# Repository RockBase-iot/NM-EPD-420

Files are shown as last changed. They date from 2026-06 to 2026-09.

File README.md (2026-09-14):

# NM-EPD-420

The **NM-EPD-420** is an **ESP32-S3** based 4.2-inch tri-color E-ink development board. It integrates Wi-Fi / BLE, LoRa, audio codec, temperature/humidity sensing, SD card, battery management, and other common peripherals — a ready-to-use hardware platform for low-power info panels, weather stations, Meshtastic terminals, dashboards, and more.

> The firmware in this repository is a **factory test firmware**. Its only purpose is to help the production line or a developer quickly verify that all on-board peripherals work after powering on. See [Section 4](#4-factory-test-firmware) for the test sequence, workflow, and build instructions.
>
> 中文版本: [README_cn.md](README_cn.md)

---

## 1. Board overview

The NM-EPD-420 packs the core resources needed for E-ink projects onto a single board:

* **MCU**: ESP32-S3 (16 MB Flash, PSRAM, dual-core 240 MHz, 2.4 GHz Wi-Fi and BLE 5)
* **Display**: 4.2" 400×300 tri-color E-ink panel (black / white / red), model **GDEY042Z98**; black-and-white E-ink panel (GxEPD2_420_GYE042A87); and a four-color panel (black / white / red / yellow, GxEPD2_420c_GDEY0420F51). All three use the same pin definitions, but the controller protocol must match — select the variant according to the panel actually fitted.
* **Audio**: ES8311 audio codec + external Class-D amplifier + onboard speaker, plus an LMD4737 PDM digital microphone
* **Environment sensor**: AHT20 temperature/humidity sensor with independent power switch
* **Wireless extension**: Header for **SX126x** family LoRa modules (shares SPI bus with the SD card) (optional)
* **Storage & I/O**: µSD card slot, USER / BOOT buttons, battery ADC, JST 1.25 2-Pin battery connector
* **Low-power design**: Independent enable pins for each peripheral module allow complete power-down before ESP32 deep sleep

You can run one of the already-supported projects listed below, or treat the NM-EPD-420 as a general ESP32-S3 carrier and start your own application using the pin definitions in this document.

### Display refresh performance

The NM-EPD-420 currently supports the tri-color GDEY042Z98 panel, the black-and-white GYE042A87 panel, and the four-color GDEY0420F51 panel. Their refresh characteristics are as follows:

- **GDEY042Z98 tri-color panel**:
  - **SKU: NM-EPD-420**
  - Full refresh (black / white / red) takes approximately 10 seconds; partial refresh is not supported.
  - The tri-color panel provides richer visuals for weather stations, dashboards, and similar applications, but refreshes more slowly and is best suited to mostly static content.
  - The standard NM-EPD-420 tri-color version does not include a LoRa module and is intended for general desktop applications.

- **GYE042A87 black-and-white panel**:
  - **SKU: NM-EPD-420-BW**
  - Full refresh (black / white) takes approximately 2-3 seconds, with partial refresh supported in approximately 1 second (download [nm-epd420-bw-demo](https://github.com/RockBase-iot/nm-epd420-bw-demo) to try it).
  - The black-and-white panel is recommended for applications that need faster content updates.
  - The NM-EPD-420-BW version is suitable for fast-refresh applications and includes LoRa support by default, making it suitable for indoor desktop LoRa nodes.

- **GDEY0420F51 four-color panel**:
  - **SKU: NM-EPD-420-4C**
  - Full refresh (black / white / red / yellow) takes approximately 25-30 seconds; partial refresh is not supported.
  - The four-color panel is recommended for applications that need more colors and do not require frequent updates.
  - **Build environment: `nm-epd-420-4c`**; driver: `GxEPD2_420c_GDEY0420F51` (400×300, black / white / red / yellow).
  - Build with `pio run -e nm-epd-420-4c`; T1 checks white, black, red, and yellow full-screen fills, then black/red/yellow text.

The NM-EPD-420 base board has also been validated with a 7.5-inch tri-color panel (GxEPD2_750c_Z08, GD7965 controller). The test confirmed base-board compatibility and driver feasibility — content refreshes and displays normally.
*Note: the 7.5-inch panel is not the standard panel shipped with NM-EPD-420 and is used for testing only. For real applications, adjust the case and mechanical structure as needed.*

---

## 2. Already supported open-source projects

The following projects have been ported to the NM-EPD-420. Clone the linked branch and build:

| Project | Description | Adapted repository / branch |
|---|---|---|
| **Meshtastic** | Off-grid LoRa mesh messaging; shows node info, messages, and sensor data on the 4.2" E-ink panel (HT-RA62 module, SX1262) | [RockBase-iot/meshtastic-firmware@`nm-epd-420`](https://github.com/RockBase-iot/meshtastic-firmware/tree/nm-epd-420) |
| **TRMNL-Firmware** | TRMNL E-ink content framework; fetches images/content from a server on a schedule | [RockBase-iot/trmnl-firmware](https://github.com/RockBase-iot/trmnl-firmware) |
| **Biscuit** | Multi-purpose tool / entertainment firmware for E-ink devices | [RockBase-iot/biscuit@`master`](https://github.com/RockBase-iot/biscuit/tree/master) |
| **ESP32-weather-epd** | Low-power weather station; fetches data from OpenWeatherMap and displays it on E-ink | [RockBase-iot/esp32-weather-epd@`main`](https://github.com/RockBase-iot/esp32-weather-epd/tree/main) |
| **ESP32-Dashboard** | Multi-function E-ink dashboard: weather, air quality, indoor T/RH, Web config portal, etc. | [RockBase-iot/ESP32-Dashboard@`main`](https://github.com/RockBase-iot/ESP32-Dashboard/tree/main) |
| **MeshCore** | Lightweight, low-power LoRa gateway firmware | [RockBase-iot/meshcore-firmware@`nm-epd-420`](https://github.com/RockBase-iot/meshcore/tree/nm-epd-420) |
| **AgentDeck** | Displays your AI coding agent on a physical screen | [puritysb/AgentDeck](https://github.com/puritysb/AgentDeck) |
| **nm-epd420-bw-demo** | NM-EPD420 black-and-white panel demo: partial refresh and fast refresh | [RockBase-iot/nm-epd420-bw-demo](https://github.com/RockBase-iot/nm-epd420-bw-demo) |
| **Inkstone-firmware** | Local-push multi-color E-ink display framework | [RockBase-iot/Inkstone-firmware](https://github.com/RockBase-iot/Inkstone-firmware) |

**Application firmware for the related projects is already available on [RockBase IoT Web Flash](https://flash.rockbaseiot.com).**

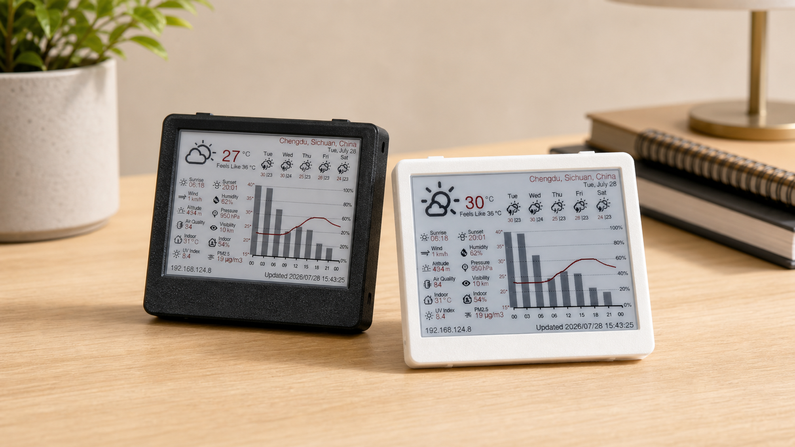
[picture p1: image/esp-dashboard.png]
ESP32-Dashboard Application


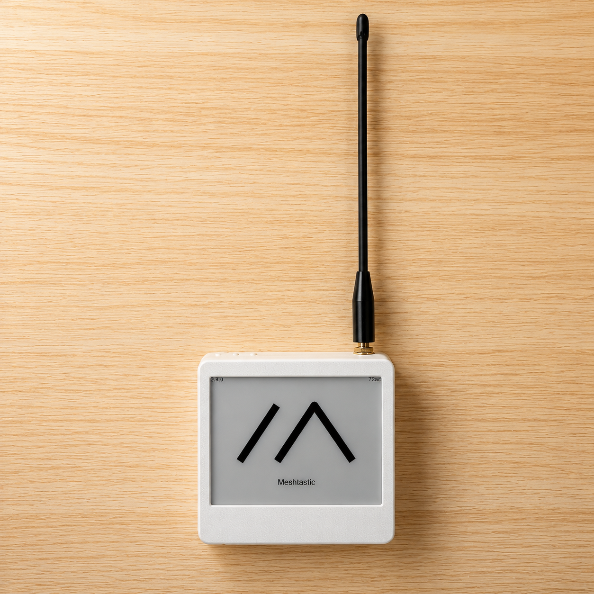
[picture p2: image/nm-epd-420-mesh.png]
Meshtastic Application


---

## 3. Hardware resources and pin definitions

### 3.1 Block diagram

```
                      ┌───────────────────────────────────┐
                      │             ESP32-S3              │
                      │  (16 MB Flash, PSRAM, BLE/Wi-Fi)  │
                      └───────────────────────────────────┘
        SPI2 (FSPI) ──┐    SPI3 (HSPI) ──┐    I²C ──┐    I²S ──┐
                      ▼                  ▼          ▼          ▼
              ┌──────────────┐    ┌──────────┐  ┌──────┐  ┌────────┐
              │ EPD GDEY042  │    │ µSD card │  │AHT20 │  │ ES8311 │ → PA → SPK
              │   Z98 (3C)   │    │  + LoRa  │  └──────┘  │  codec │ ← DMIC LMD4737
              │  400×300 4.2"│    │  modem   │            │        │
              └──────────────┘    └──────────┘            └────────┘

  ┌────────┐  ┌────────┐  ┌──────────────┐
  │  USER  │  │  BOOT  │  │ Battery ADC  │
  │ button │  │ button │  │  IO43+IO3    │
  └────────┘  └────────┘  └──────────────┘
```

### 3.2 Bill of materials

| Block | Part | Interface | Notes |
|---|---|---|---|
| MCU | **ESP32-S3** (qio_opi PSRAM)  | — | 16 MB flash, dual-core 240 MHz |
| E-paper | **GDEY042Z98** 4.2" 400×300 | SPI (FSPI) | Tri-color B/W/R, GxEPD2 driver |
| Codec | **ES8311** | I²C 0x18 + I²S  | DAC out → external PA → 8 Ω speaker |
| Mic | **LMD4737** PDM DMIC | I²S (DMIC mode) | Sample rate 16 kHz |
| T/RH sensor  | **AHT20** | I²C 0x38 | Power-gated via `PIN_TEMP_CTL` |
| SD card | µSD | SPI (HSPI) | Shared bus with LoRa |
| LoRa modem | HT-RA62 **SX1262** family | SPI (HSPI) | CS / RST / BUSY / DIO1 GPIOs |
| Buttons | USER, BOOT | GPIO | Active LOW, external pull-up |
| Audio amp | External Class-D | EN GPIO | Enabled by `PIN_PA_CTRL` HIGH |

### 3.3 ESP32-S3 GPIO map

> Authoritative source: [src/config.h](src/config.h).

| Group | Signal | GPIO | Direction | Notes |
|---|---|---|---|---|
| EPD (FSPI) | SCK | 2 | OUT | |
| | MOSI | 1 | OUT | |
| | MISO | — | — | Panel pin NC (write-only) |
| | CS | 46 | OUT | |
| | DC | 4 | OUT | |
| | RST | 5 | OUT | |
| | BUSY | 6 | IN | HIGH while refresh in progress |
| SD + LoRa (HSPI)| SCK | 9 | OUT | Shared bus |
| | MOSI | 10 | OUT | |
| | MISO | 11 | IN | |
| | SD CS | 7 | OUT | |
| | LoRa NSS | 8 | OUT | |
| | LoRa RST | 12 | OUT | |
| | LoRa BUSY | 13 | IN | |
| | LoRa DIO1 | 14 | IN | Used by specific LoRa applications |
| I²S (ES8311) | MCLK | 21 | OUT | 4.096 MHz (256 × 16 kHz) |
| | BCLK | 15 | OUT | |
| | LRCK / WS | 17 | OUT | |
| | DOUT (ESP→DAC) | 18 | OUT | ES8311 DSDIN |
| | DIN  (ADC→ESP) | 16 | IN | ES8311 ASDOUT |
| I²C | SDA | 39 | I/O | AHT20 + ES8311 shared bus |
| | SCL | 38 | OUT | |
| | TEMP_CTL | 40 | OUT | AHT20 power gate (HIGH = on) |
| Audio | PA_CTRL | 41 | OUT | External amplifier enable |
| User I/O | USER button | 45 | IN | Active LOW, external pull-up |
| | BOOT button | 0 | IN | Active LOW, RTC GPIO, external pull-up  |
| Module EN | LoRa EN | 47 | OUT | LoRa module power enable (HIGH = on) |
| | Codec EN | 44 | OUT | ES8311 power enable (HIGH = on) |
| | ADC EN | 43 | OUT | Battery ADC circuit enable (HIGH = on)  |
| Battery ADC | BATT_ADC | 3 | IN | Battery voltage sense (resistor divider)|

*Note: Applications may use different peripherals. Control unused peripherals through their enable pins to optimize power consumption.*

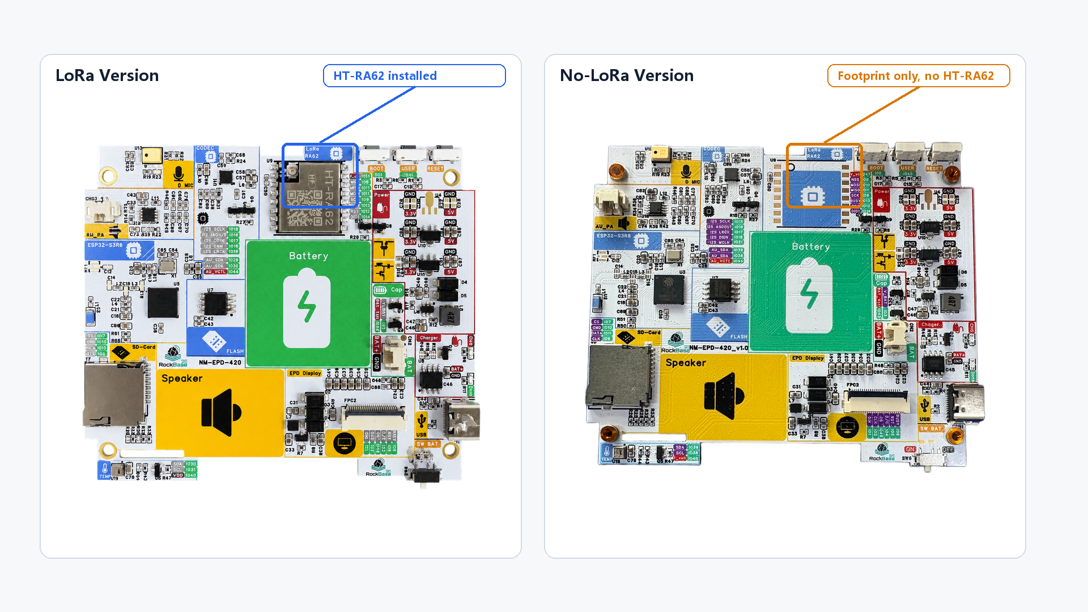
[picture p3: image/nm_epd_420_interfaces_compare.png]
Two Version interfaces


The LoRa version includes an HT-RA62 module (SX1262) for Meshtastic, MeshCore, and other LoRa applications. The no-LoRa version does not include the module and is intended for general applications. The NM-EPD-420-BW version supports LoRa by default so LoRa applications can benefit from its faster display refresh.

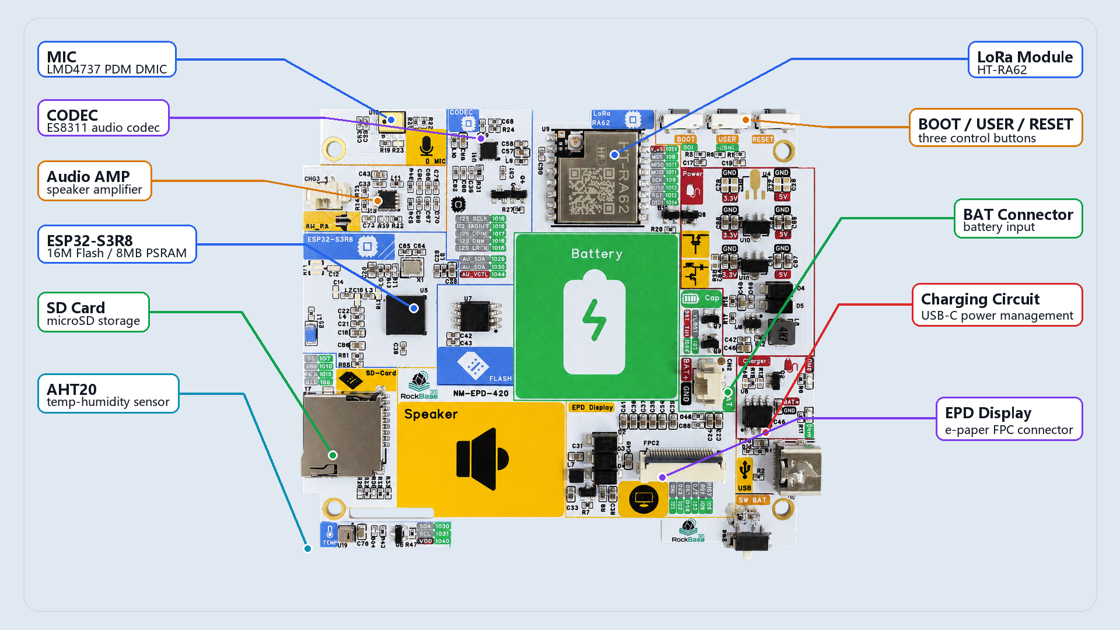
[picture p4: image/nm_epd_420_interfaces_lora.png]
LoRa Version interfaces


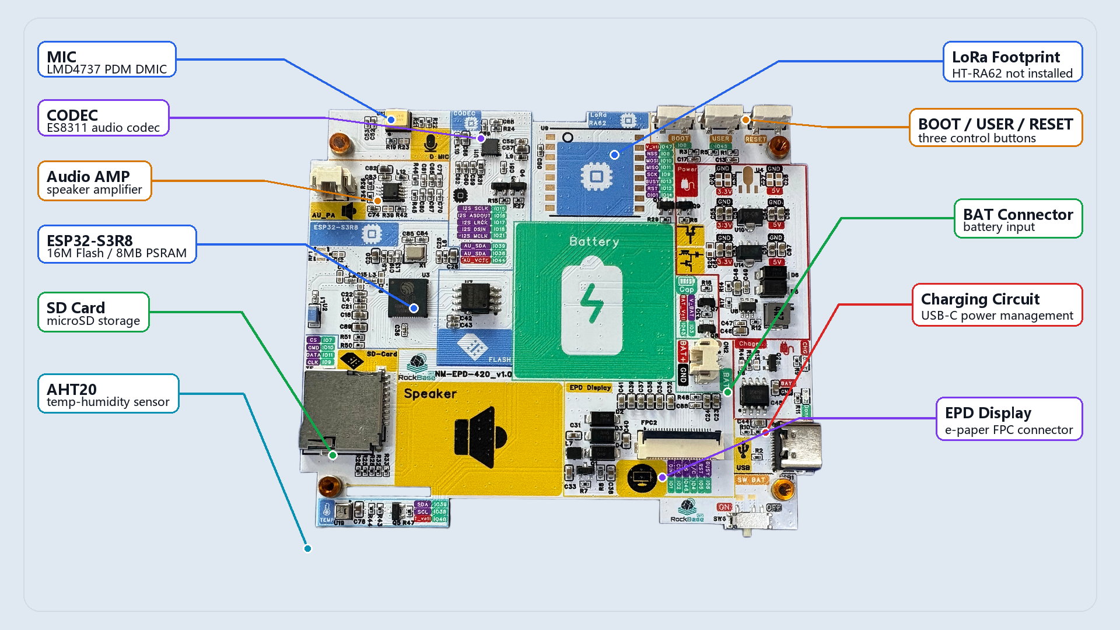
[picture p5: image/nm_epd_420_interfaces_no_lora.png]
No LoRa Version interfaces


### 3.4 Accessories and power

* **3D case**: STL files are in [docs/case](docs/case), including buttons, top plate, back cover, etc.; ready for direct 3D printing.
* **Battery**: A 3.7 V Li-Po battery with protection circuit, capacity ≥ 500 mAh, is recommended. The PCB has a JST 1.25 PH 2-Pin connector (red = positive, black = negative). Recommended size: 603030. [Buy on AliExpress JST 1.25 2Pin 603030 600mAh](https://www.aliexpress.com/item/32853151195.html)

### 3.5 7.5-inch tri-color panel extension test

The NM-EPD-420 base board has been validated with a 7.5-inch tri-color panel (GxEPD2_750c_Z08, GD7965 controller), confirming base-board compatibility and driver feasibility. Test results show that content refreshes and displays normally.

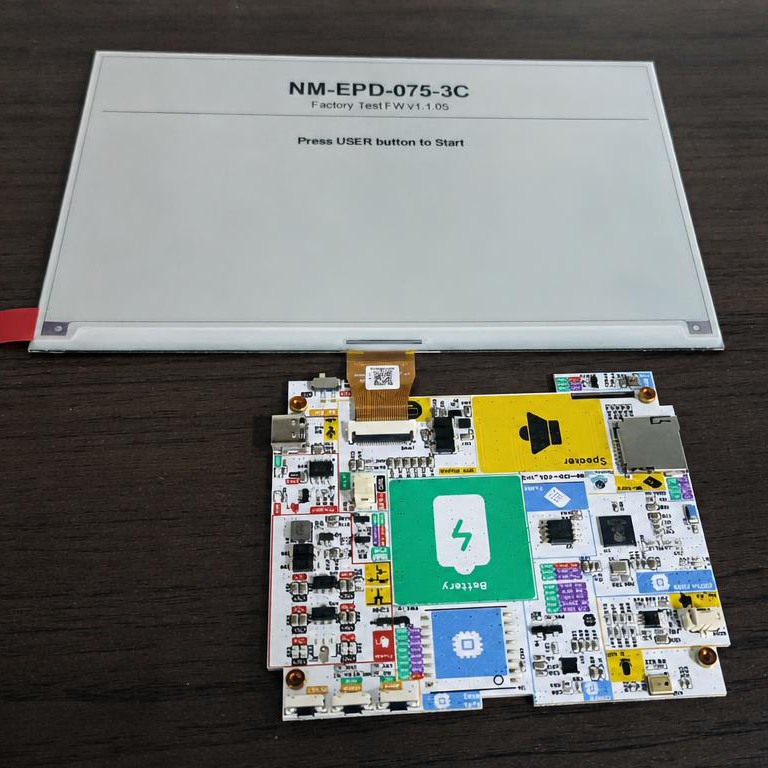
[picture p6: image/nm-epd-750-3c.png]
7.5-inch tri-color panel test


---

## 4. Factory test firmware

The firmware in this repository exercises every on-board peripheral in a fixed sequence (T0…T11). It renders a dedicated screen for every step and lets the operator confirm / reject each step with the **USER** and **BOOT** buttons. At the end, a one-page summary screen lists every test as PASS / FAIL / SKIP.

### 4.1 Test sequence

| Test | Item | Description | Screen |
|---|---|---|---|
| T0 | System startup  | Serial / EPD init, welcome screen, wait USER | T0 |
| T1 | EPD display | White / Black / Red fill + text demo | — |
| T3 | Buttons | USER key and BOOT key press detection | — |
| T4 | ES8311 codec | Sweep 500/1k/2k/3k Hz + *Ode to Joy* melody  | T4 |
| T5 | DMIC mic | Voice record + speaker loopback + RMS check  | T5 |
| T6 | AHT20 sensor | Temperature & humidity over I²C | T6 |
| T7 | Battery ADC | Battery divider voltage on IO3 (enable IO43) | — |
| T8 | Wi-Fi scan | 2.4 GHz AP scan, expect ≥ 1 network | T8 |
| T9 | SD card R/W | HSPI mount + write / read-back verify | T9 |
| T10  | LoRa SPI bus | Reset modem, check BUSY low | — |
| T11  | Summary | Per-item PASS/FAIL/SKIP table + EPD hibernate + deep sleep | T11 |

A complete run typically takes ~3 min, dominated by EPD full-refresh time (~10 s per page on a 3-color panel).

### 4.2 Operator workflow

```
                  ┌───────────────────────────┐
   power on  ───► │  T0  Welcome              │  press USER
                  └───────────────────────────┘
                             │
                             ▼
                  ┌───────────────────────────┐
                  │  T1 … T10                 │
                  │  for each test:           │
                  │    show screen            │
                  │    run hardware           │
                  │    USER = PASS / OK       │
                  │    BOOT = FAIL            │
                  └───────────────────────────┘
                             │
                             ▼
                  ┌───────────────────────────┐
                  │  T11  Summary             │  EPD hibernate → ESP32 deep sleep
                  └───────────────────────────┘
```

Buttons are debounced (5 × 10 ms samples) and gated against EPD `BUSY` so a press during a refresh cannot be consumed as a verdict for the next test.

### 4.3 Build & flash

Prerequisites: PlatformIO Core (command line) or VS Code + PlatformIO extension.

```powershell
# In the repository root:
$env:IDF_GITHUB_ASSETS = "dl.espressif.cn/github_assets"   # optional, China mirror
pio run                                                    # build
pio run --target upload --upload-port COM38                # flash
pio device monitor --baud 115200                           # serial console
```

The first build downloads the ESP-IDF toolchain (~hundreds of MB) into `%USERPROFILE%\.platformio`. Subsequent builds take ~25 s.

Typical serial output during a run:

```
[FACTORY TEST] Board: NM-EPD-420
[FACTORY TEST] FW: v1.4.01
[FACTORY TEST] T0 - System startup OK
…
[FACTORY TEST] T1 START - EPD Display
[T1] Round 1/4 - Filling screen WHITE ...
[T1] BUSY self-check: sawHigh=1  highMs=2873
…
[FACTORY TEST] ===== SUMMARY =====
[FACTORY TEST] T1   EPD Display    [PASS]
…
[FACTORY TEST] Overall: FACTORY_TEST=OK
```

---

## 5. Developing your own project on NM-EPD-420

This board is essentially a fully-featured ESP32-S3 carrier. To start your own project:

1. Pick one of the already-supported projects from [Section 2](#2-already-supported-open-source-projects) and clone the corresponding branch, or create a fresh PlatformIO / Arduino project.
2. Copy the pin configuration below into your project's `config.h` or `platformio.ini`. For PlatformIO projects, see the `codes` directory; `nm_epd_420.json` already defines the board pin mapping and can be referenced directly.
3. Initialize the SPI / I²C / I²S buses as needed. Remember: **EPD uses FSPI, SD + LoRa share HSPI**.
4. Drive the corresponding module-enable pin HIGH before using a peripheral, and LOW afterwards to save power.
5. Use `esp_deep_sleep_start()` or similar APIs for low-power operation.

### 5.1 Common peripheral initialization notes

* **E-paper**: Use the `zinggjm/GxEPD2` library with `GxEPD2_420c_GDEY042Z98` for the default tri-color NM-EPD-420 and `GxEPD2_420_GYE042A87` for NM-EPD-420-BW. The four-color panel can use `GxEPD2_420c_GDEY0420F51` with the `nm-epd-420-4c` environment. CS=46, DC=4, RST=5, BUSY=6; the four-color driver uses active-low BUSY.
* **AHT20**: Use `Adafruit AHTX0`; I²C SDA=39, SCL=38; set `PIN_TEMP_CTL(40)` HIGH before reading.
* **ES8311 / speaker / microphone**: I²C address 0x18, I²S pins as in the table above; drive `PIN_CODEC_EN(44)` and `PIN_PA_CTRL(41)` HIGH before playback.
* **SD card**: Use the `SD` library + HSPI (SCK=9, MOSI=10, MISO=11, CS=7).
* **LoRa**: SX126x family on the shared HSPI bus; CS=8, RST=12, BUSY=13, DIO1=14; drive `PIN_LORA_EN(47)` HIGH before use.
* **Battery ADC**: Drive `PIN_ADC_EN(43)` HIGH, read from `PIN_BATT_ADC(3)`, divide ratio is 2:1.

### 5.2 Software architecture (test firmware)

If you need to modify or extend the factory test firmware, the source is organized as follows:

```
src/
├── main.cpp              ← Arduino entry; disables task WDT, calls runner.run()
├── test_runner.{h,cpp}   ← T0/T11, button helpers, EPD pre-test resync, dispatch
├── config.h              ← Pin map + feature switches (first-hand reference for your own development)
├── spi_buses.h           ← Shared HSPI bus init for SD + LoRa
├── ui/
│   └── display_helper.h  ← EPD wrapper + showWelcome / showTestScreen
└── tests/
    ├── test_t1_epd.h     ← header-only test implementations
    ├── …
    └── test_t10_lora.h
```

Design notes:

* **Single-threaded, blocking.** The factory line is human-paced; using `delay()` and synchronous SPI/I²S keeps the code linear and easy to debug.
* **Tests are header-only.** Each `test_tN_*.h` exposes `TestResult runTestTN(Display&, TestRunner&)` and is included once from `test_runner.cpp`. No virtual dispatch.
* **EPD resync between tests.** `TestRunner::_preTest()` re-runs `_epd.init(..., initial_power_on=true, ...)` so peripheral tests that touch shared resources (Wi-Fi RF cal, HSPI for SD, …) cannot leave the EPD in a desynced state.
* **Button gating against EPD BUSY.** All button reads are debounced (5 × 10 ms) and rejected while `PIN_EPD_BUSY` is HIGH, so a press during the ~10 s full-window refresh cannot leak into the next verdict.

### 5.3 Frameworks & libraries

| Layer | Version |
|---|---|
| Build system | **PlatformIO** |
| Platform | `pioarduino/platform-espressif32` **54.03.21** |
| Framework | Arduino-ESP32 **3.2.x** (on top of ESP-IDF 5.4)|
| Language | C++17 |

Library deps (see [platformio.ini](platformio.ini)):

| Library | Version | Used by |
|---|---|---|
| `zinggjm/GxEPD2` | 1.6.8 | EPD |
| `adafruit/Adafruit AHTX0` | 2.0.5 | T6 sensor |
| `adafruit/Adafruit BusIO` | 1.17.4  | (dep) |
| `adafruit/Adafruit Unified Sensor` | 1.1.15  | (dep) |
| `SPI`, `Wire`, `WiFi`, `SD` | 3.2.1 | bundled |
| `Adafruit GFX Library` | 1.12.6  | (dep) |

### 5.4 Sharing your code

If you want to share your code with the community more quickly, check out the [RockBase IoT ESPWebApps](https://github.com/RockBase-iot/ESPWebApps) project. Develop your application following the existing framework and conventions, and users will be able to flash it online through [RockBase IoT Web Flash](https://flash.rockbaseiot.com).

---

## 6. Repository layout

```
NM-EPD-420/
├── README.md            ← this file
├── README_cn.md         ← Chinese version
├── platformio.ini       ← PlatformIO build configuration
├── docs/                ← Design/debug notes, 3D case files
├── image/               ← Screen captures shown in this README
│   ├── T0.png  T2.png  T4.png  T5.png  T6.png  T8.png  T9.png  T11.png
└── src/                 ← All firmware sources
```

---

## 7. Where to buy

The first batch of NM-EPD-420 units went on sale as scheduled in August 2026 and is now available for order. You can purchase through the following channels:

* [Amazon RockBase IoT](https://www.amazon.com/gp/product/B0H1QCHMW6)
* [RockBase IoT Store](https://www.aliexpress.com/store/1105401362)
* [RockBase Shop](https://rockbase.shop/products/nm-epd-420/)
* [NMTech Global Store](https://www.aliexpress.com/store/1104265822)

# Changelog

## 2026-9-14

- Added `NM-EPD-420-4C` four-color E-ink support test; released [Inkstone-firmware](https://github.com/RockBase-iot/Inkstone-firmware), supporting web preview and image push for multi-color devices;
- Added 7.5-inch tri-color panel validation (GxEPD2_750c_Z08, GD7965 controller);
- Added support for the [nm-epd420-bw-demo](https://github.com/RockBase-iot/nm-epd420-bw-demo) project, making it easy to test and verify partial refresh and fast refresh on the black-and-white `NM-EPD-420-BW`.

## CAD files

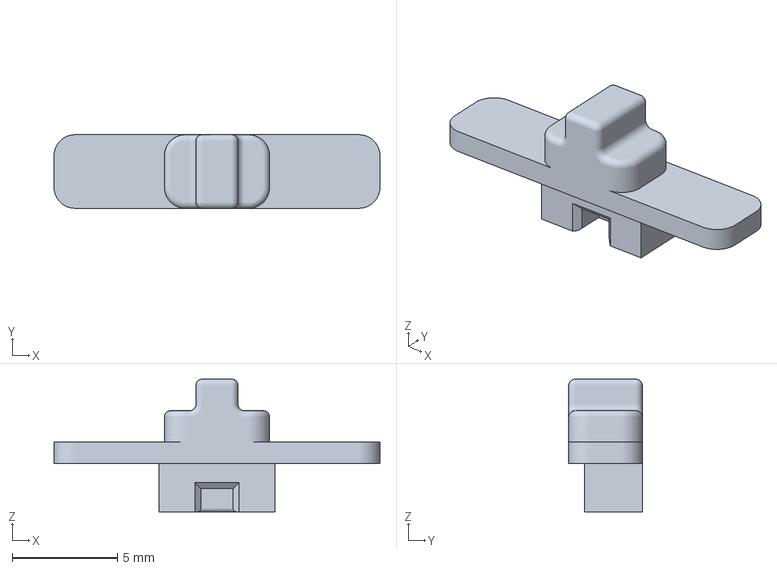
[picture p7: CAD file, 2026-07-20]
docs/case/desk-onoff-cover.3mf
15.5 x 3.50 x 6.31 mm

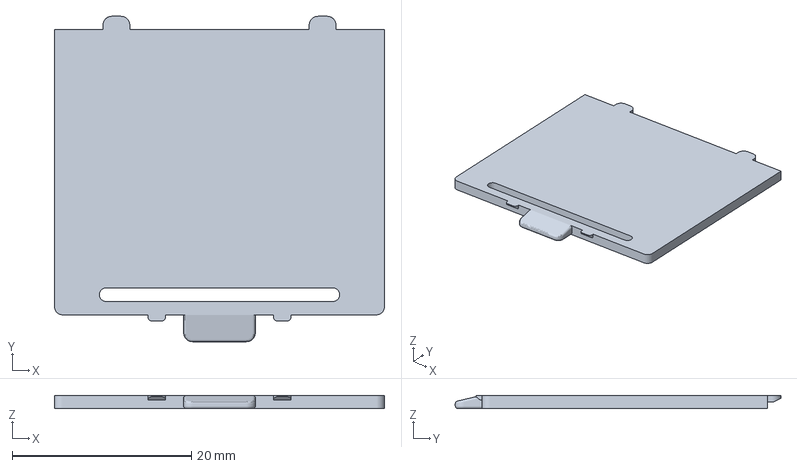
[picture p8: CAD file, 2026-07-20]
docs/case/battery-nog.3mf
36.8 x 36.3 x 1.50 mm

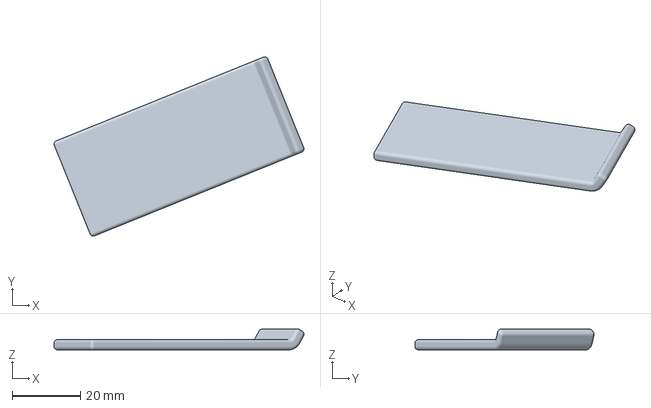
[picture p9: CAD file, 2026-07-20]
docs/case/desk-nog.3mf
73.2 x 52.5 x 6.10 mm

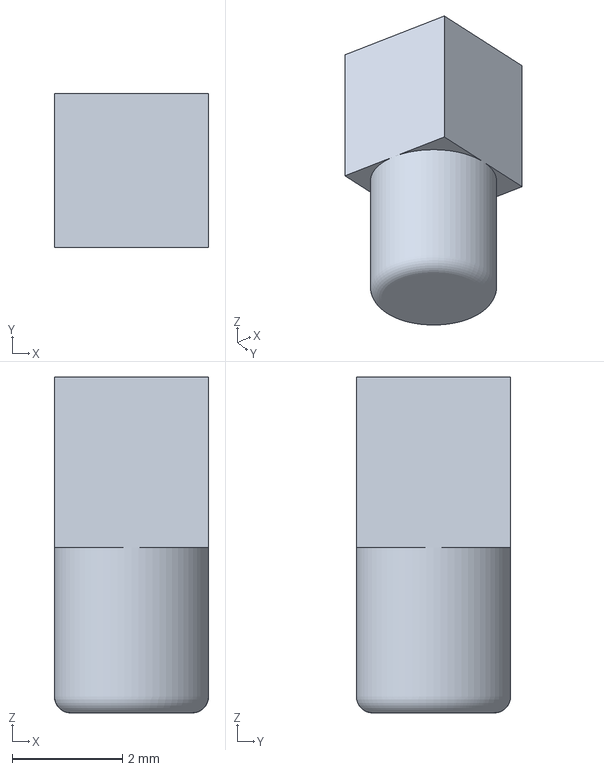
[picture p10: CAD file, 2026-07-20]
docs/case/desk-key-cover.3mf
2.80 x 2.80 x 6.10 mm

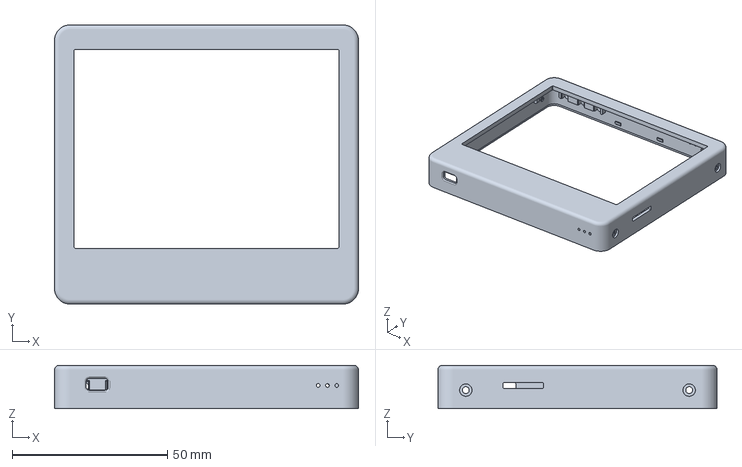
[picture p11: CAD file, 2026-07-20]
docs/case/desk-front-cover.3mf
98.0 x 90.0 x 14.0 mm

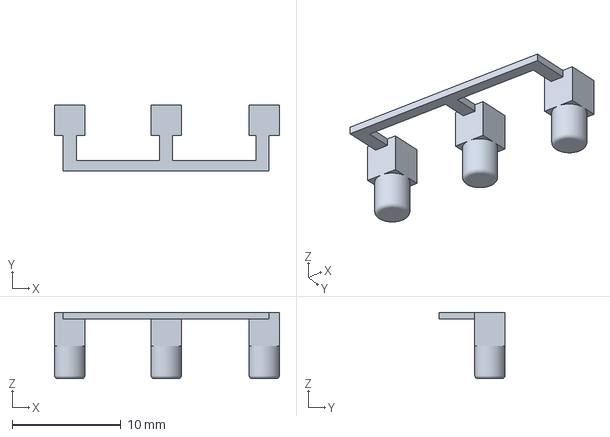
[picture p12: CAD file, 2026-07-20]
docs/case/desk-key-cover-2.3mf
20.7 x 6.10 x 6.10 mm

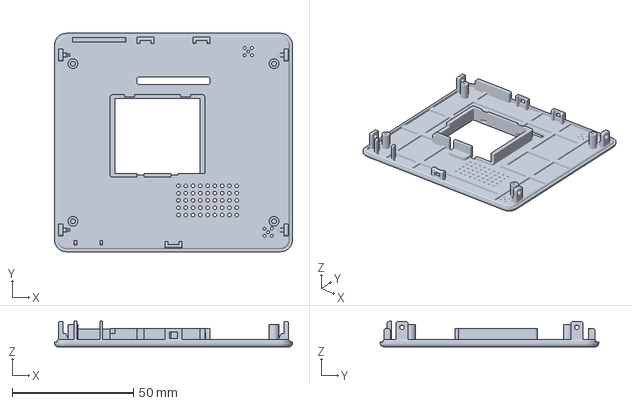
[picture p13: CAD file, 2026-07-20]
docs/case/desk-back-cover.3mf
98.0 x 90.0 x 10.6 mm

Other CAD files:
docs/case/desk-front-cover-2.3mf

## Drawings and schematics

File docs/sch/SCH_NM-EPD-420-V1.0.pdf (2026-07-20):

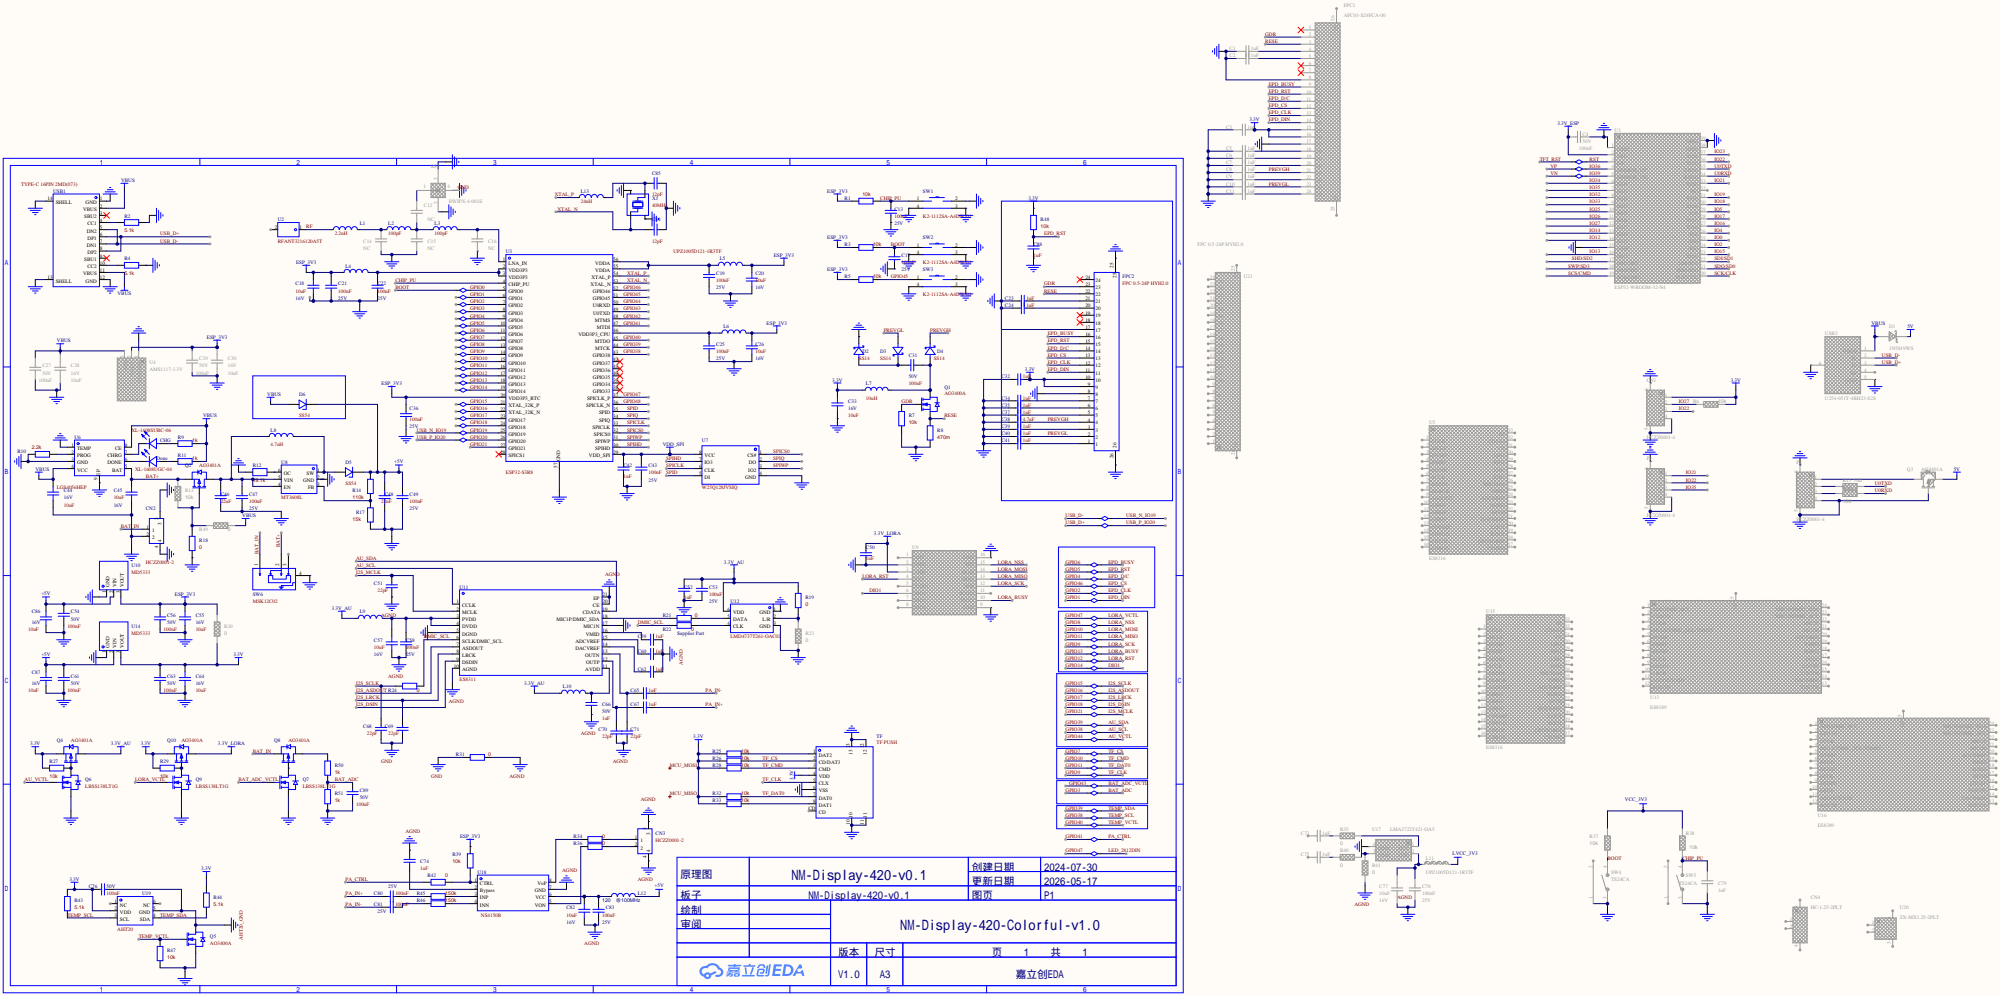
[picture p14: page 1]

板子 | NM-Display-420-v0.1 | 图页 | P1
绘制 | | NM-Display-420-Colorful-v1.0
审阅

V1.0 | A3 | 嘉立创EDA

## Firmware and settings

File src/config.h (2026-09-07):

#pragma once

// ─── Firmware version ────────────────────────────────────────────────────────
#define FW_VERSION  "v1.4.05"

#ifndef NM_EPD_420_BW
#define NM_EPD_420_BW 0
#endif

#ifndef NM_EPD_420_4C
#define NM_EPD_420_4C 0
#endif

#ifndef NM_EPD_075_3C
#define NM_EPD_075_3C 0
#endif

#if NM_EPD_075_3C
#define BOARD_NAME  "NM-EPD-075-3C"
#elif NM_EPD_420_4C
#define BOARD_NAME  "NM-EPD-420-4C"
#elif NM_EPD_420_BW
#define BOARD_NAME  "NM-EPD-420-BW"
#else
#define BOARD_NAME  "NM-EPD-420"
#endif

// ─── EPD (SPI0 / VSPI) ───────────────────────────────────────────────────────
#define PIN_EPD_SCK   2
#define PIN_EPD_MOSI  1
#define PIN_EPD_MISO  -1  // EPD is write-only and panel pin is NC; do NOT claim
                          //   a GPIO here — GPIO10 is used by the peripheral
                          //   HSPI bus (SD MOSI), and any overlap leaves the
                          //   FSPI bus in a bad state after SD operations.
#define PIN_EPD_CS   46
#define PIN_EPD_DC    4
#define PIN_EPD_RST   5
#define PIN_EPD_BUSY  6

// ─── SD card + LoRa (FSPI, shared bus) ───────────────────────────────────────
#define PIN_SD_CLK    9
#define PIN_SD_MOSI   10   // CMD
#define PIN_SD_MISO   11   // DAT0
#define PIN_SD_CS     7

#define PIN_LORA_NSS  8    // LoRa chip-select (CS), shares FSPI bus with SD
#define PIN_LORA_RST  12
#define PIN_LORA_BUSY 13
#define PIN_LORA_DIO1 14   // Not used in SPI connectivity test

// ─── I2S (ES8311 CODEC) ──────────────────────────────────────────────────────
// HW net mapping (per schematic): GPIO16=I2S_ASDOUT (ES8311 pin7, ADC->ESP),
//                                  GPIO18=I2S_DSIN  (ES8311 pin9, ESP->DAC)
#define PIN_I2S_MCLK  21
#define PIN_I2S_BCLK  15
#define PIN_I2S_LRCK  17
#define PIN_I2S_DOUT  18   // ESP TX → ES8311 DSDIN (pin 9)
#define PIN_I2S_DIN   16   // ES8311 ASDOUT (pin 7) → ESP RX

// ─── I2C (AHT20 + ES8311 shared bus) ─────────────────────────────────────────
#define PIN_I2C_SDA   39
#define PIN_I2C_SCL   38
#define PIN_TEMP_CTL  40   // AHT20 power enable (HIGH = on)

// ─── GPIO ────────────────────────────────────────────────────────────────────
#define PIN_PA_CTRL   41   // External amplifier enable (HIGH = on)
#define PIN_BOOT_BTN   0   // BOOT key, external pull-up, pressed = LOW (RTC GPIO)
#define PIN_USER_BTN  45   // USER key, external pull-up, pressed = LOW

// ─── Module enable pins (active HIGH) ────────────────────────────────────────
#define PIN_LORA_EN   47   // LoRa module power enable (HIGH = on)
#define PIN_CODEC_EN  44   // ES8311 codec power enable (HIGH = on)
#define PIN_ADC_EN    43   // Battery ADC circuit enable (HIGH = on)

// ─── Battery voltage ADC ─────────────────────────────────────────────────────
#define PIN_BATT_ADC   3   // Battery voltage sense input (via resistor divider)
#define BATT_ADC_DIV   2   // Divider ratio: ADC_mV * BATT_ADC_DIV = battery mV
#define BATT_MIN_MV    2500
#define BATT_MAX_MV    4500
#define BATT_OFF_MAX_MV 300
#define BATT_ADC_DISCHARGE_MS 100
#define BATT_ADC_SETTLE_MS     80
#define BATT_ADC_SAMPLES       24
#define BATT_ADC_MAX_SPREAD_MV 250

// ─── EPD refresh tuning ─────────────────────────────────────────────────────
// Full-height page buffer reduces paged transfer overhead on ESP32-S3.
// The selected GDEY042Z98 driver still does full 3-color refresh, so this
// improves latency moderately but cannot remove the panel's inherent delay.
#if NM_EPD_075_3C
#define EPD_PAGE_HEIGHT           480   // 480 = full buffer for 800x480 GxEPD2_750c_Z08
#else
#define EPD_PAGE_HEIGHT           300   // 300 = full buffer, 150 = half buffer
#endif
#define EPD_FAST_FULL_UPDATE      1     // 1 = use fast full-refresh waveform
#define EPD_DRIVER_MODE           2     // 0=SSD1683 1=UC8179 2=auto detect

// ─── Feature switches ─────────────────────────────────────────────────────────
#define BATTERY_ADC_AVAILABLE  1   // 1 = test (IO3 + enable IO43)

// ─── DMIC recording thresholds ────────────────────────────────────────────────
#define DMIC_RMS_THRESHOLD_VOICE     150   // Phase-1: operator voice
#define DMIC_RMS_THRESHOLD_LOOPBACK   50   // Phase-2: speaker loopback

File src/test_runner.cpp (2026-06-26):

#include "test_runner.h"
#include "config.h"
#include "spi_buses.h"
#include <esp_sleep.h>
#include <driver/gpio.h>
#include <freertos/FreeRTOS.h>
#include <freertos/task.h>

// Definition for the second SPI bus (HSPI / SPI3) shared by SD + LoRa.
// EPD keeps using the default `SPI` global (FSPI / SPI2).
SPIClass spiPeripheral(HSPI);

// ─── Test implementations (header-only stubs) ─────────────────────────────────
#include "tests/test_t1_epd.h"
#include "tests/test_t3_button.h"
#include "tests/test_t4_codec.h"
#include "tests/test_t5_dmic.h"
#include "tests/test_t6_aht20.h"
#include "tests/test_t7_adc.h"
#include "tests/test_t8_wifi.h"
#include "tests/test_t9_sd.h"
#include "tests/test_t10_lora.h"

// ─── Button helpers ───────────────────────────────────────────────────────────
//
// Button reads are gated on the EPD BUSY pin being LOW. This panel
// (GDEY042Z98) drives BUSY HIGH while it is refreshing — and a full-window
// refresh takes ~10–15 s, during which the MCU is blocking inside
// firstPage()/nextPage(). If the operator presses USER/BOOT during that
// window, the press is still active when control returns to the next
// waitForUser()/waitForVerdict(), and the very first poll in those loops
// would consume it as a "new" press, putting the test sequence one step
// ahead of the UI. Treating any sample taken while BUSY=HIGH as "not
// pressed" makes that whole class of stale presses invisible.
//
// Debounce: a candidate press must satisfy BUSY=LOW AND button=LOW at
// every one of N samples taken 10 ms apart (~50 ms total). This rejects
// the millisecond-scale bounce/EMI on the BUSY falling edge and on key
// release that would otherwise sneak past a 2-sample 20 ms window.

static const uint8_t  BTN_DEBOUNCE_SAMPLES = 5;
static const uint8_t  BTN_DEBOUNCE_STEP_MS = 10;

static bool _btnPressedDebounced(uint8_t pin) {
    // Quick reject: BUSY already high, or button already high.
    if (Display::isPanelBusy())      return false;
    if (digitalRead(pin) != LOW)           return false;

    // Stable-low debounce: BUSY must stay low and button must stay low for
    // BTN_DEBOUNCE_SAMPLES consecutive samples.
    for (uint8_t i = 1; i < BTN_DEBOUNCE_SAMPLES; i++) {
        delay(BTN_DEBOUNCE_STEP_MS);
        if (Display::isPanelBusy()) return false;
        if (digitalRead(pin) != LOW)           return false;
    }
    return true;
}

bool TestRunner::userPressed() { return _btnPressedDebounced(PIN_USER_BTN); }
bool TestRunner::bootPressed() { return _btnPressedDebounced(PIN_BOOT_BTN); }

// Raw (no BUSY-gate, no debounce) — only used for the release gate below
// so we can see whether the operator's finger is still on the key.
static bool _btnHeldRaw(uint8_t pin) { return digitalRead(pin) == LOW; }

// Block until both keys are released. Catches the case where the user
// pressed during a refresh and is still holding when BUSY falls — we want
// the first "press" we report to be a fresh release→press edge.
static void _waitAllReleased() {
    while (_btnHeldRaw(PIN_USER_BTN) || _btnHeldRaw(PIN_BOOT_BTN)) delay(10);
    delay(30);  // mechanical/EMI settle after release
}

void TestRunner::waitForUser() {
    _waitAllReleased();
    while (!userPressed()) { delay(10); }
    delay(50);  // debounce
    while (userPressed()) { delay(10); }  // wait for release
}

bool TestRunner::waitForVerdict() {
    _waitAllReleased();
    while (true) {
        if (userPressed()) {
            delay(50);
            while (userPressed()) { delay(10); }
            return true;
        }
        if (bootPressed()) {
            delay(50);
            while (bootPressed()) { delay(10); }
            return false;
        }
        delay(10);
    }
}

// ─── T0 — System startup & welcome screen ────────────────────────────────────

void TestRunner::runT0() {
    // 1. Serial
    Serial.begin(115200);
    delay(200);

    // 2. PA_CTRL default LOW (amplifier off)
    pinMode(PIN_PA_CTRL, OUTPUT);
    digitalWrite(PIN_PA_CTRL, LOW);

    // 3. Button pins
    pinMode(PIN_USER_BTN, INPUT_PULLUP);
    pinMode(PIN_BOOT_BTN, INPUT_PULLUP);

    // 4. Init EPD and show welcome screen
    _display.init();
    _display.showWelcome();

    // 4b. Init the second SPI bus (HSPI) shared by SD card and LoRa.
    // Doing it once here means T9/T10 don't need to call SPI.end()/begin()
    // and the EPD's default SPI bus stays untouched.
    initPeripheralSpi();

    // 5. Serial log
    Serial.println();
    Serial.println("========================================");
    Serial.print  ("[FACTORY TEST] Board: "); Serial.println(BOARD_NAME);
    Serial.print  ("[FACTORY TEST] FW: ");    Serial.println(FW_VERSION);
    Serial.println("[FACTORY TEST] T0 - System startup OK");
    Serial.println("[FACTORY TEST] Waiting for USER key to start...");
    Serial.println("========================================");

    // 6. Wait for USER key press
    waitForUser();

    Serial.println("[FACTORY TEST] T0 PASS - Starting test sequence");
}

// ─── Deep sleep with GPIO hold ────────────────────────────────────────────────
// Ensures all module/peripheral enables are LOW (or SPI CS HIGH) and latches
// the pin states so they are maintained while the IO power domain is off
// during deep sleep. Mirrors the pattern used in the ESP32-Dashboard BSP for
// this same board (nm_display_420/Board.cpp).
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

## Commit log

2026-05-25 hw-rev2: remove LED T2, add enable pins, ADC test, deep sleep
    - config.h: remove PIN_LED/WS2812; add PIN_LORA_EN(IO47), PIN_CODEC_EN(IO44),
    PIN_ADC_EN(IO43), PIN_BATT_ADC(IO3), BATT_ADC_DIV; PIN_EPD_CS moved to IO46;
    BATTERY_ADC_AVAILABLE=1
    - test_t2_led: deleted (WS2812 hardware permanently removed)
    - test_runner.h/cpp: remove T2_LED state and runT2(); T11 summary updated to
    9 tests, result indexed by test number
    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
2026-05-28 docs: update READMEs for hw-rev2 (rm T2/WS2812, add enable pins, ADC, deep sleep)
2026-06-24 build: 编译后自动合并生成 nm420-factory.bin (地址 0x0)
2026-06-25 feat: replace deep sleep with EPD aging checkerboard mode in T11 summary
    - T11 now waits for USER key then enters EPD aging loop (BLACK/WHITE, RED/WHITE, BLACK/RED checkerboards)
    - Remove _enterDeepSleep() and related includes (esp_sleep.h, driver/gpio.h)
    - Bump firmware version to v1.4.02
    - Update README to reflect new T11 flow
    [config.h, test_runner.cpp]
2026-06-25 refactor: remove text overlay from EPD aging checkerboard
    Pure checkerboard pattern without text labels for cleaner aging/burn-in cycle
    [test_runner.cpp]
2026-06-25 feat: add boot shortcut for epd aging mode
    [config.h, test_runner.cpp]
2026-06-25 feat: streamline factory test flow
2026-06-26 feat(epd): add auto-detection for UC8179/SSD1683 driver and BUSY pin abstraction
    - Add Display::isPanelBusy() static method to abstract BUSY level differences
    - Implement automatic driver validation via BUSY pin activity probe during welcome screen
    - When EPD_DRIVER_MODE=2, auto-detect and retry with alternate driver on validation failure
    - Add _primeControlPins() to properly initialize CS/DC/RST/BUSY pins
    - Increase UC8179 SPI clock from 10MHz to 25MHz
    [display_helper.h, test_runner.cpp]
2026-07-20 update README and 3D files
    [battery-nog.3mf, desk-back-cover.3mf, desk-front-cover-2.3mf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]
2026-09-07 Test 7.5inch 3C EPD on nm-epd board
